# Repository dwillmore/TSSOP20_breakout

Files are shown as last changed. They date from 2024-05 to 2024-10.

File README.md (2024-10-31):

# TSSOP20_breakout
A generic breakout board for TSSOP20 chips to a SIP header meant for breadboard use

New V3 coming shortly

## Features
- USB-C connection for power and/or data (proper dual 5.1K CC termination resistors)
- SO-23-5 regulator with optional stabilization capacitor
- four pin debug header with power, ground, and two additonal signals
- fully uncommitted power, ground, and USB data pins
- test pads on the back side to connect power, ground, and USB signals, etc.
- bypassable regulator (place a diode across the input to output to bypass and provide backfeed protection to the USB power
- optional component pad--useful for low speed USB for chips which lack a PHY and need a 1.5K pullup to signal bus presance
- 20x0.1" SIP header for mounting off the edge of a breadboard.  This allows the bulk of the breadboard to be use for interconnects and prototyping.
  
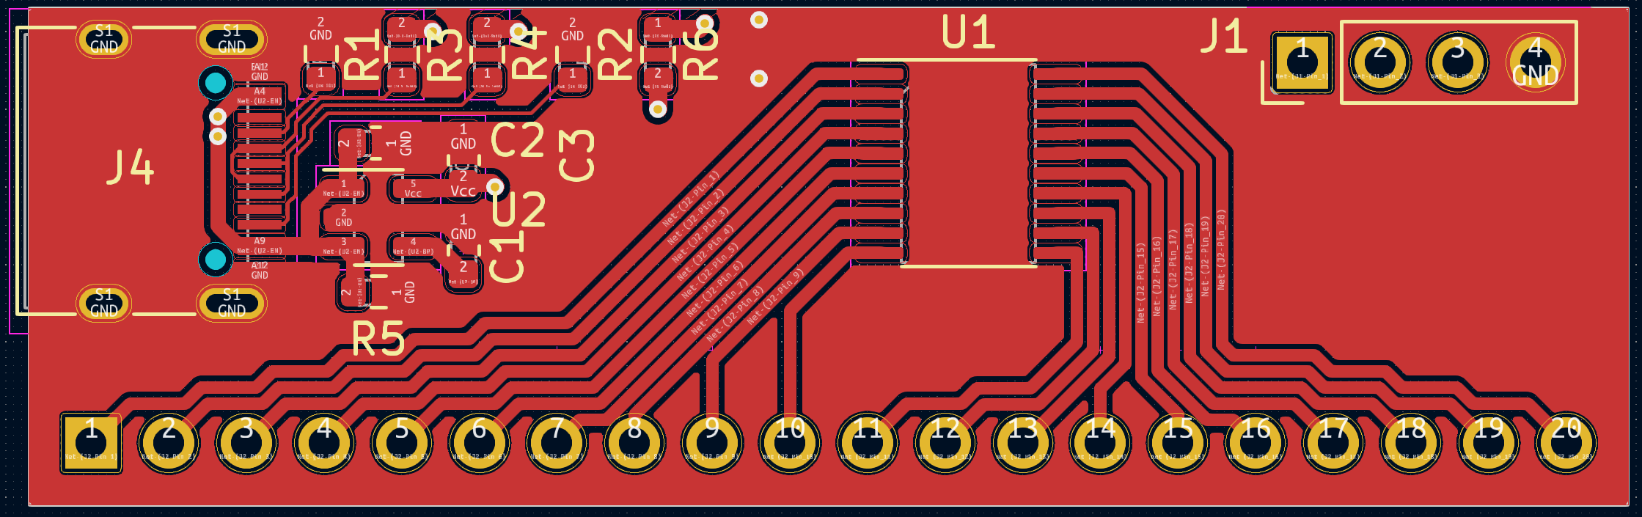
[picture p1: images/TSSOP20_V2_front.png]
TSSOP20_V2_front

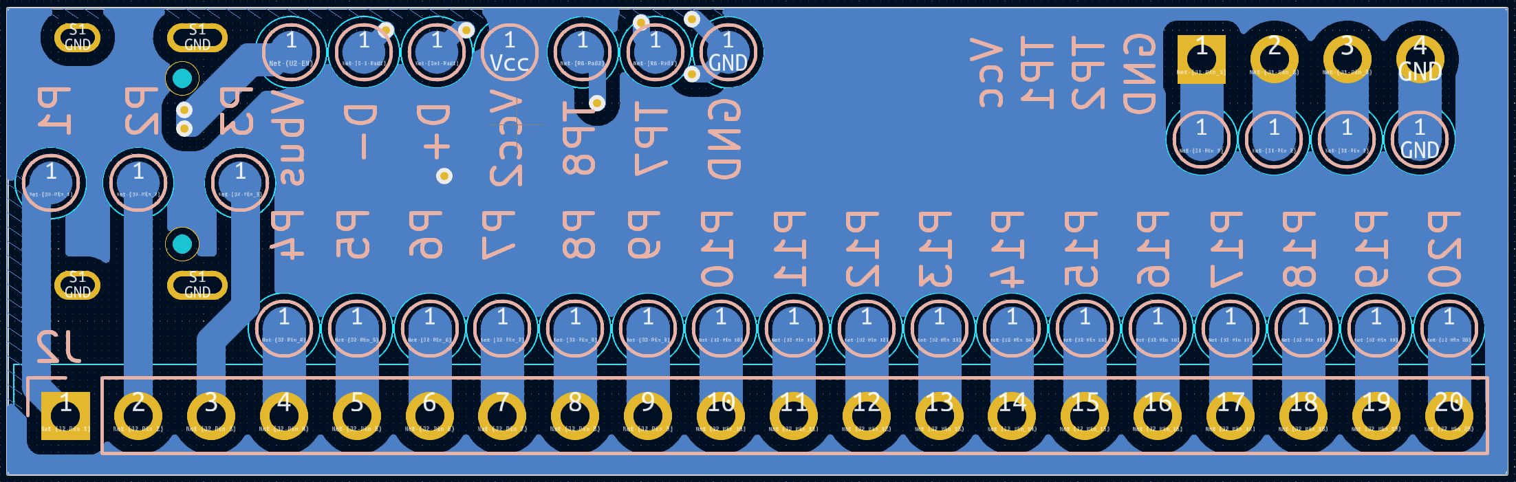
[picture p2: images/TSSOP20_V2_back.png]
TSSOP20_V2_back

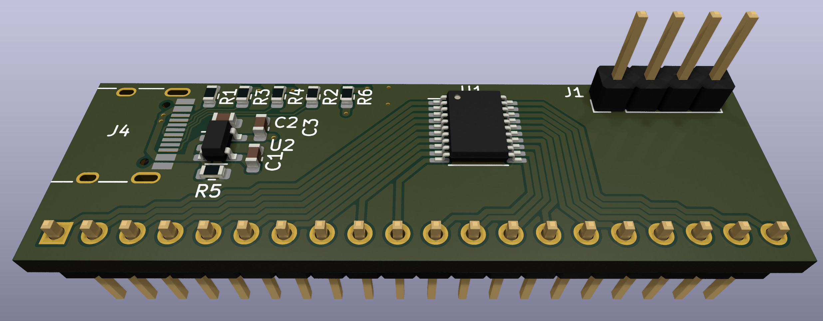
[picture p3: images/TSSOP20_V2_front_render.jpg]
TSSOP20_V2_front_render

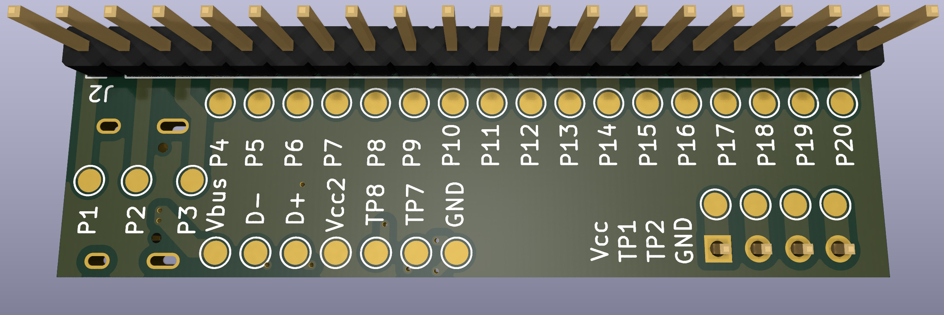
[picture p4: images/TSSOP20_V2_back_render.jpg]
TSSOP20_V2_back_render


# Example boards
## CH32V203, CH32X033, and CH32V003

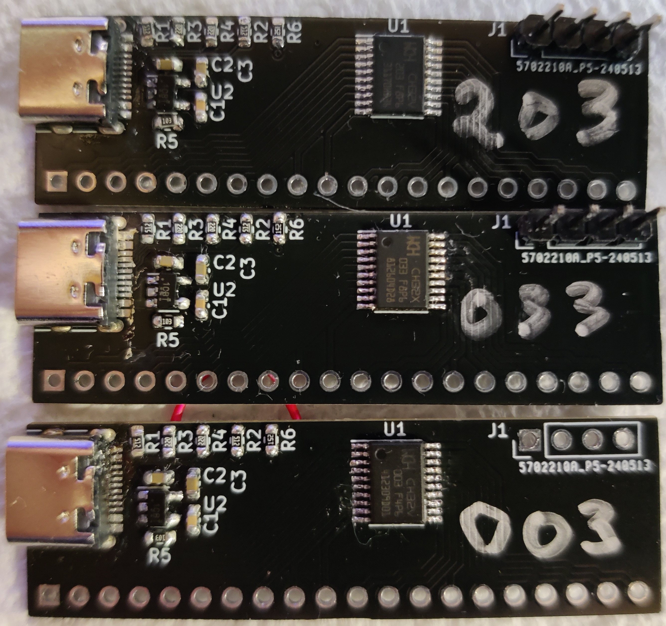
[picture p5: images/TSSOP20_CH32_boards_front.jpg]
TSSOP20_V2_back_render

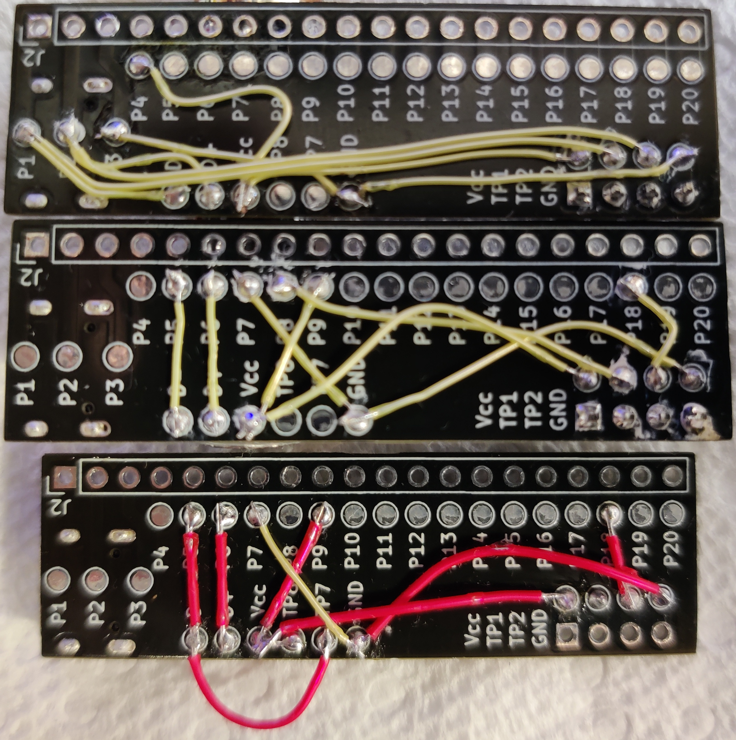
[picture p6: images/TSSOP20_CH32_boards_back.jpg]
TSSOP20_V2_back_render


# BOM
This is more of a guidance than a specific BOM as it will vary with the features needed on the board and the needs of the specific chip being used.

## USB-C parts
- J4 -- USB-C USB2.0 receptacle Example: LCSC C2988369 Mfr. Part#: GT-USB-7010ASV
- R1, R2 -- USB CC1/2 termination resistors 5.1 KOhm Example: LCSC
- R3, R4 -- USB serial termination resistors 22 Ohm Example LCSC C3016215 Mfr. Part #: SCR0603F22R
- R6 -- USB speed signaling resistor 1.5 KOhm 0603 generic resistor (see other R part numbers)

## Power regulator parts
- R5 --  (not needed due to schematic error) Regulator Enable pullup resistor 10 KOhm Example: LCSC C3017715 Mfr. Part #: SCR0603J10K
- C1 -- Regulator Bypass stabilization capacitor 22 nF Example: LCSC C302021 Mfr. Part #: 0603B223K500CT
- C2, C3 -- Regulator Bypass capacitor 1 uF Example: LCSC C59782 Mfr. Part #: CL10B105KO8NNNC
- U2 -- SO23-5 regulator Example: 3.3V RT9193-33PB (needs C1), TLV743P33PDVB (does not need C1)

## SIP header and programming header
- J1, J2 -- I don't have specific part numbers for these because I have boxes of them and I just use what I need.  It's a generic 0.1"
 pin header, nothing special.

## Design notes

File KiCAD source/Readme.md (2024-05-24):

These are the KiCAD 7.0 source for the board V2

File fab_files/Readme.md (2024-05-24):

These fabrication files have been generated for JLCPCB using their 2 layer process with KiCad 7.0.

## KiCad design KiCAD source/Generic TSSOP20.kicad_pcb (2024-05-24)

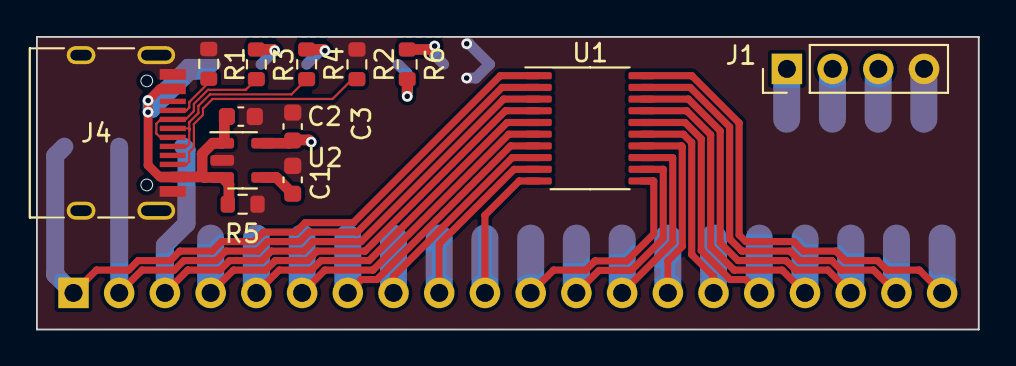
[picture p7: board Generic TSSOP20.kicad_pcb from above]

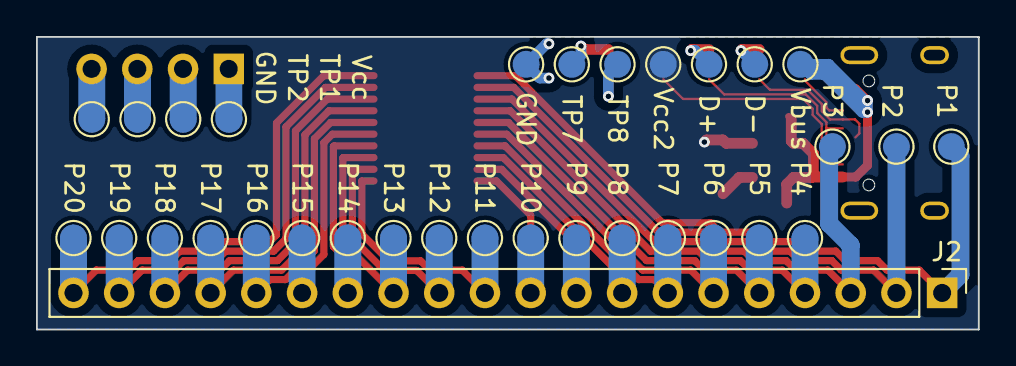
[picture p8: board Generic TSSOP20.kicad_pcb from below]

Board: 2 copper layers, 52.3 x 16.3 mm, 45 parts (32 on the bottom side), 35 nets.

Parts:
C1, C2, C3: C_Small; C_0603_1608Metric
D+: D+; TestPoint_Pad_D1.5mm
D-: D-; TestPoint_Pad_D1.5mm
GND: GND; TestPoint_Pad_D1.5mm
GND#2: GND; TestPoint_Pad_D1.5mm
J1: Conn_01x04_Pin; PinHeader_1x04_P2.54mm_Vertical
J2: Conn_01x20_Pin; PinHeader_1x20_P2.54mm_Vertical
J4: USB_C_Receptacle_USB2.0; USB_C_Receptacle_HRO_TYPE-C-31-M-12
P1, P2, P3, P4, P5, P6, P7, P8, P9, P10, P11, P12, P13, P15, P16, P18, P20: TestPoint_Pad_D1.5mm
P14, P17, P19: GND; TestPoint_Pad_D1.5mm
R1, R2, R3, R4, R5, R6: R_US; R_0603_1608Metric
TP1: Test/Prog1; TestPoint_Pad_D1.5mm
TP2: Test/Prog2; TestPoint_Pad_D1.5mm
TP7: USB_Pullup; TestPoint_Pad_D1.5mm
TP8: USB_PullupN; TestPoint_Pad_D1.5mm
U1: CH32V003F4P6; TSSOP-20_4.4x6.5mm_P0.65mm
U2: SOT-23-5
Vbus: Vbus; TestPoint_Pad_D1.5mm
Vcc, Vcc2: Vcc; TestPoint_Pad_D1.5mm

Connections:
/Vcc: C3.2, U2.5 (Vout), Vcc2.1
GND: C1.1, C2.1, C3.1, GND.1, GND#2.1, J1.4, J4.A1 (GND), J4.A12 (GND), J4.B1 (GND), J4.B12 (GND), J4.S1 (SHIELD), R1.2, R2.2, R5.1, U2.2 (GND)
unnamed: D+.1, R4.2
unnamed: D-.1, R3.2
unnamed: J1.1, Vcc.1
unnamed: J1.2, TP1.1
unnamed: J1.3, TP2.1
unnamed: J2.1, P1.1, U1.1 (PD4)
unnamed: J2.2, P2.1, U1.2 (PD5)
unnamed: J2.3, P3.1, U1.3 (PD6)
unnamed: J2.4, P4.1, U1.4 (PD7)
unnamed: J2.5, P5.1, U1.5 (PA1)
unnamed: J2.6, P6.1, U1.6 (PA2)
unnamed: J2.7, P7.1, U1.7 (Vss)
unnamed: J2.8, P8.1, U1.8 (PD0)
unnamed: J2.9, P9.1, U1.9 (Vdd)
unnamed: J2.10, P10.1, U1.10 (PC0)
unnamed: J2.11, P11.1, U1.11 (PC1)
unnamed: J2.12, P12.1, U1.12 (PC2)
unnamed: J2.13, P13.1, U1.13 (PC3)
unnamed: J2.14, P14.1, U1.14 (PC4)
unnamed: J2.15, P15.1, U1.15 (PC5)
unnamed: J2.16, P16.1, U1.16 (PC6)
unnamed: J2.17, P17.1, U1.17 (PC7)
unnamed: J2.18, P18.1, U1.18 (PD1)
unnamed: J2.19, P19.1, U1.19 (PD2)
unnamed: J2.20, P20.1, U1.20 (PD3)
unnamed: J4.A5 (CC1), R1.1
unnamed: J4.B5 (CC2), R2.1
unnamed: J4.A6 (D+), J4.B6 (D+), R4.1
unnamed: J4.A7 (D-), J4.B7 (D-), R3.1
unnamed: R6.1, TP7.1
unnamed: R6.2, TP8.1
unnamed: C1.2, U2.4 (BP)
unnamed: C2.2, J4.A4 (VBUS), J4.A9 (VBUS), J4.B4 (VBUS), J4.B9 (VBUS), R5.2, U2.1 (Vin), U2.3 (EN), Vbus.1

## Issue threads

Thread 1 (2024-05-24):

Alternate USB Connector

steveschnepp, 2024-05-24:
Would it be possible to map an alternate micro/mini usb connector under the existing usb-c one ?

So one has the 2 choices, as soldering usb-c is not a rookie task.

steveschnepp, 2024-05-25:
Closing, as we can just use the test pads on the side

dwillmore, 2024-06-30:
Just to add some notes here.  The USB-C connector I used is the middle of the road complexity one.  It only had the power, ground, CC, SBC, and data lines available.  It's not the full up one with the high speed data pairs, but it's also not the really simplified one that lacks the data lines.  I don't think there's room on the reverse side for the simplified connector.  You'd need to make a variant of this board.

I have soldered dozens of these USB-C connectors on boards using this pinout and it's not hard to do with just a soldering iron, normal solder, and some solder wick.  It's easier with a fine paste applicator and air, but I've always need *some* level of cleanup with wick--possibly that's a lack of skill issue on my part.  So, I'd say it's not trivial, but it's not that hard.  All SMT soldering is easier with lots of flux, though.

dwillmore, 2024-07-01:
Have you tried it with a litle flux and some braid?  Just solder all the pins well with extra flux, then apply a little flux to somme braid and suck out any extra solder.   I've never had any boards assembled for me, so I can't advise you on any of that.

Closed 2024-05-25.

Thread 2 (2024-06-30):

BOM

petiepooo, 2024-06-30:
Do you have a list of recommended part numbers, or a link to a shared Mouser project with the BOM?  Please?  This is a fantastic idea, and I'm planning to make a few.

dwillmore, 2024-06-30:
I was just thinking last night that I never did clarify that part.  I can post a generic BOM, but the board is meant to be flexable and accomodate most regulators in the common SO-23-5 footprint.  There's a pad for those which require a compensation capacitor (which can be left off for regulators that don't need it or say to leave the pin open).

You can use any 0603 parts you have handy.  You'll need to use decoupling caps which fit your specific regulator.  This is normally from 1 to 10uF, but it does vary with your part.  The voltage rating of the input may also need to vary depending on how you plan to power the board--from USB a 6.3V cap should be fine, but you may wish to power it some other way and the voltage rating would need to be adjusted appropriately.

The USB series resistors will vary with the part in question as well.  Low and full speed devices may not need them--and can just short the pads across--which high speed parts will likely need them, but they value may vary with the particular part used though they are typically 22 Ohms (again the footprint is 0603).

Then there is the 'spare' 0603 footprint.  I included this for chips which are bitbanging USB and don't have a built in USB PHY so they need some external ability to pull up one of the USB signals lines to 3.3V with a 1.5K resistor.  This footprint has patch pads on both ends and can be used to add any 0603 part to the board.  If the part needs an analog supply, this could be for a decoupling cap.

I'll try to post a BOM for the two different regulators which I have, but there is not specific BOM for this design as it's mean to adapt to the specific chip on the board and to parts that the builder may have on hand since the purpose of the board is to make them ahead of time and have them on hand when some random TSSOP20 chip falls into their lap and they need it mounted up ASAP.  You dig through bins or steal parts off of other boards (sorry unsed bluepill but all your parts are belong to me!  Oh, no someone set us up the BOM!)

petiepooo, 2024-06-30:
So it's more nuanced than just "order and mount these parts."  I get that now.  I think it would be useful to at least have the USB port's PN, still, and some examples of regulators you used in your examples.

Thanks.  I appreciate your quick response and clarification.

dwillmore, 2024-06-30:
I can and will provide a few 'typical' BOMs and some suggestions.  Thanks for bringing up this issue, I'm not sure I would have made the BOM section as useful without your prompting.

dwillmore, 2024-08-20:
@petiepooo Can you take a look at the main Readme.md to see if that satisfies yoru needs?  If so, please close the issue.  Thank you.

Closed 2024-08-21.

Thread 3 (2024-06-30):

Stencil

petiepooo, 2024-06-30:
Would be awesome to have a pre-generated solder stencil ready to download.  I love the way a board comes together on a hotplate or hot air rework station when using solder paste and a stencil.

dwillmore, 2024-06-30:
Given the low volume nature of the use of this board, I didn't think anyone would want a stencil for them, but I can certainly generate the file and add it to the repo.

dwillmore, 2024-06-30:
Okay, good news!  It seems the workflow I use--as recommended by JLCPCB--generates the stencil info.  So the .zip file in the fab_files directory has the required info already.  If you want to order a stencil, you're good to go with the info there!

There are a lot of cautions you need to know when ordering a stencil--like don't order the full sized or framed ones as they're huge and cost a ton.  You only need the little cut down one for home production of a board at a time.  I know people who've made this mistake and not only paid way more than they needed to, but got a stencil that was so large it was hard to use.  Full sized stencils are meant for automated paste application machines.  And if you have one of those, you're not using this design. :)

petiepooo, 2024-06-30:
Thanks much!

Closed 2024-06-30.

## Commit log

2024-05-24 Update README.md
    Add board images
2024-05-24 Initial commit of the KiCAD source for the V2
    [Generic TSSOP20.kicad_pcb, Generic TSSOP20.kicad_sch]
2024-06-03 Boards with CH32 chips on them
    This is a selection of CH32 boards with different TSSOP20 chips on them. CH32V003, CH32X033, and CHV203 are the chips on these boards.
2024-06-03 Update README.md
    Add example boards
2024-07-23 Update README.md
    Add BOM advice
2024-10-31 Update README.md
    got USB termination resistor value wrong.
